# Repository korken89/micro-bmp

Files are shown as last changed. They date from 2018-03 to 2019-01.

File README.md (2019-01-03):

# Micro Black Magic Probe (µBMP)

A small [Black Magic Probe](https://github.com/blacksphere/blackmagic) based on the pinout of the STLink V2 support firmware. Connections has been added for the support of SWO, while the UART pinout is also available. Designed to stick directly into a USB port, without cable.

## Changes

### v1.4.1

* Reinforced the USB-C plug's mounting pads

### v1.4

* Changed to USB-C plug

### v1.3

* Added LED on the 5V line to see when the fuse is "blown"
* Removed panelized boards, to be updated later

### v1.2

* Removed component designators to clean up the PCB, the designators are available in the Gerbers
* Consolidated components, using resistor arrays and 8ch ESD/EMI filter
* Now have ESD/EMI protection on the outputs
* Added fuse of 5V line

### v1.0

* First release
* Tested and working

## Resources

### Schematics

A PDF print of the schematic are available in `ubmp_v1_3.pdf`.

### Programming instructions

Clone and build `stlink` unless you already have it:

```bash
cd ~/git
git clone --recursive https://github.com/texane/stlink
cd stlink
make -j4
```

Clone and build the firmware for `Black Magic Probe`, note to use `stlink` as `PROBE_HOST`:

```bash
cd ~/git
git clone --recursive https://github.com/blacksphere/blackmagic.git
cd blackmagic
cd libopencm3
make -j4 lib
cd ../src
make -j4 PROBE_HOST=stlink
```

Flash the `uBMP`:

```bash
cp ../../stlink/build/Release/st-flash .
./st-flash erase
./st-flash write blackmagic_dfu.bin 0x8000000
./st-flash --reset write blackmagic.bin 0x8002000
```

## Images

### USB-C version (v1.4)
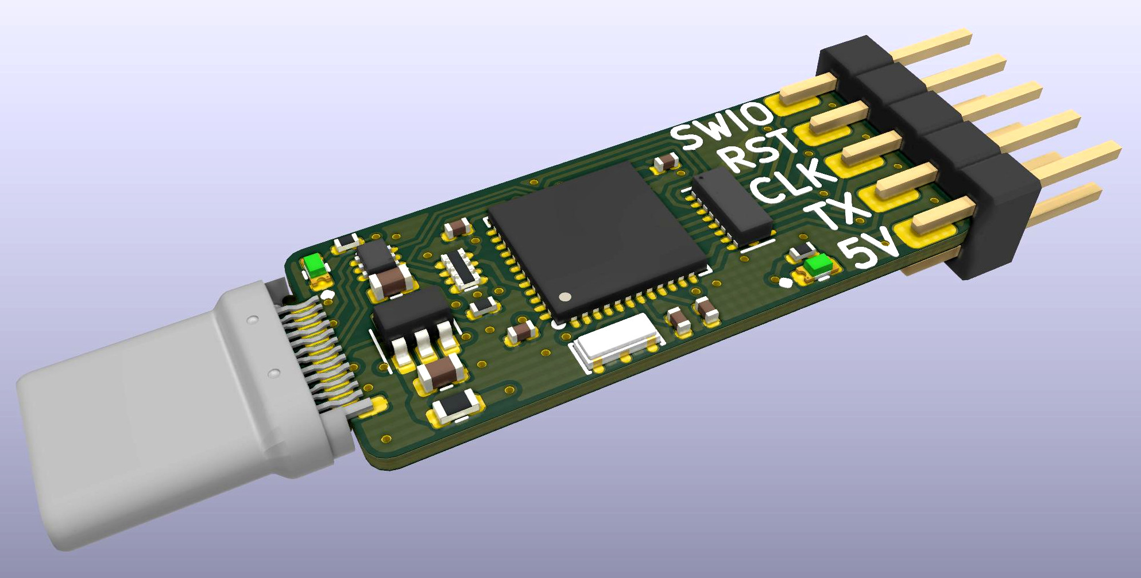
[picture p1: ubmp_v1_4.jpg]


### Second batch (v1.2)
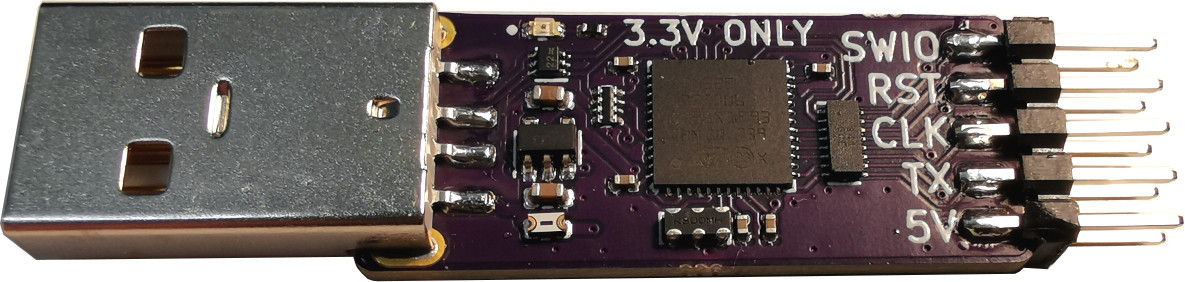
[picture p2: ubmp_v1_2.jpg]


### First batch (v1.0)

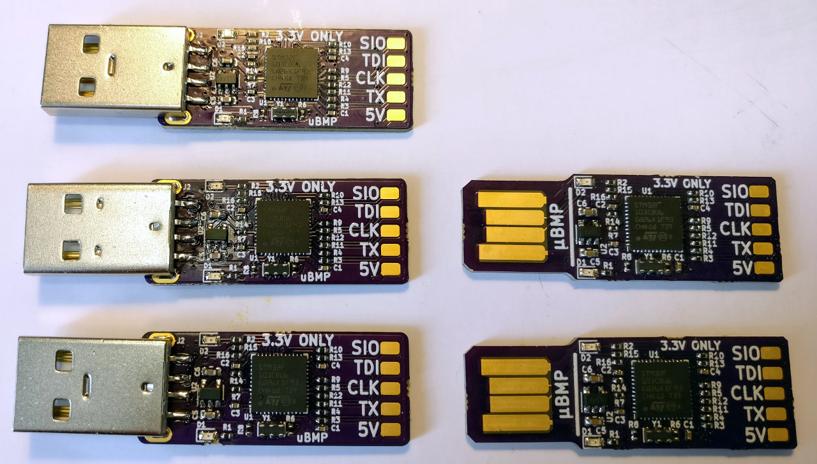
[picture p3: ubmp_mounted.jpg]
Mounted

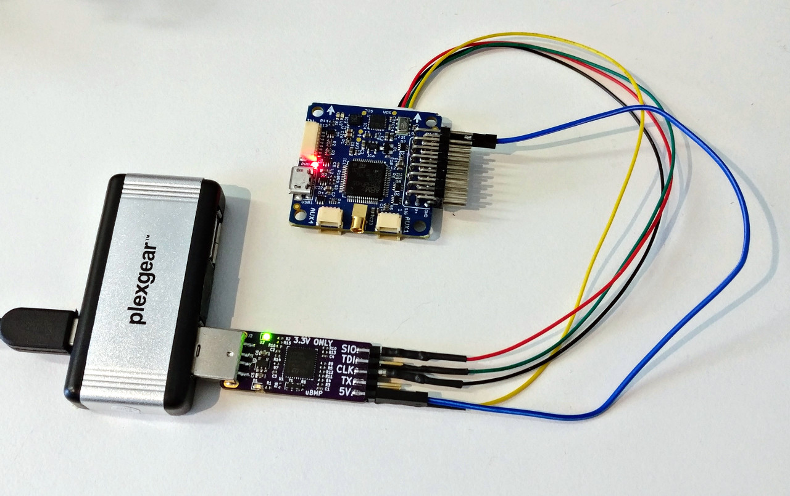
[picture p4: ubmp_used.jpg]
In use


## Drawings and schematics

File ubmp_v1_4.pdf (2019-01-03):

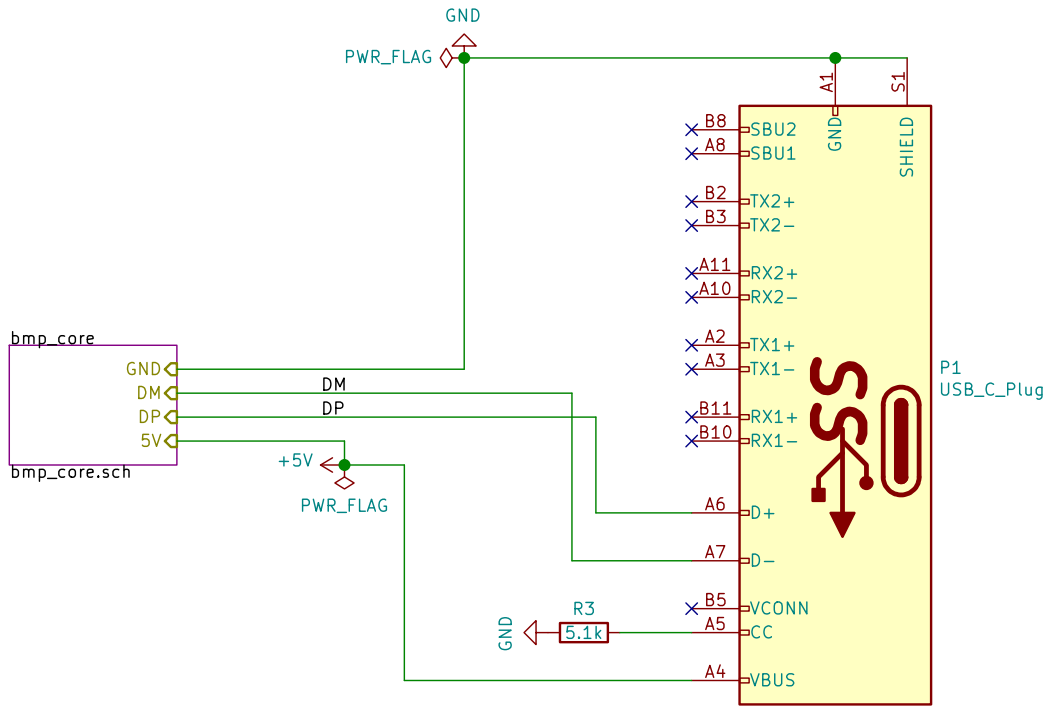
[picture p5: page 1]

Note that this board is designed to work with the
STLink V2 version of Black Magic Probe firmware.
Design available at: github.com/korken89/micro-bmp

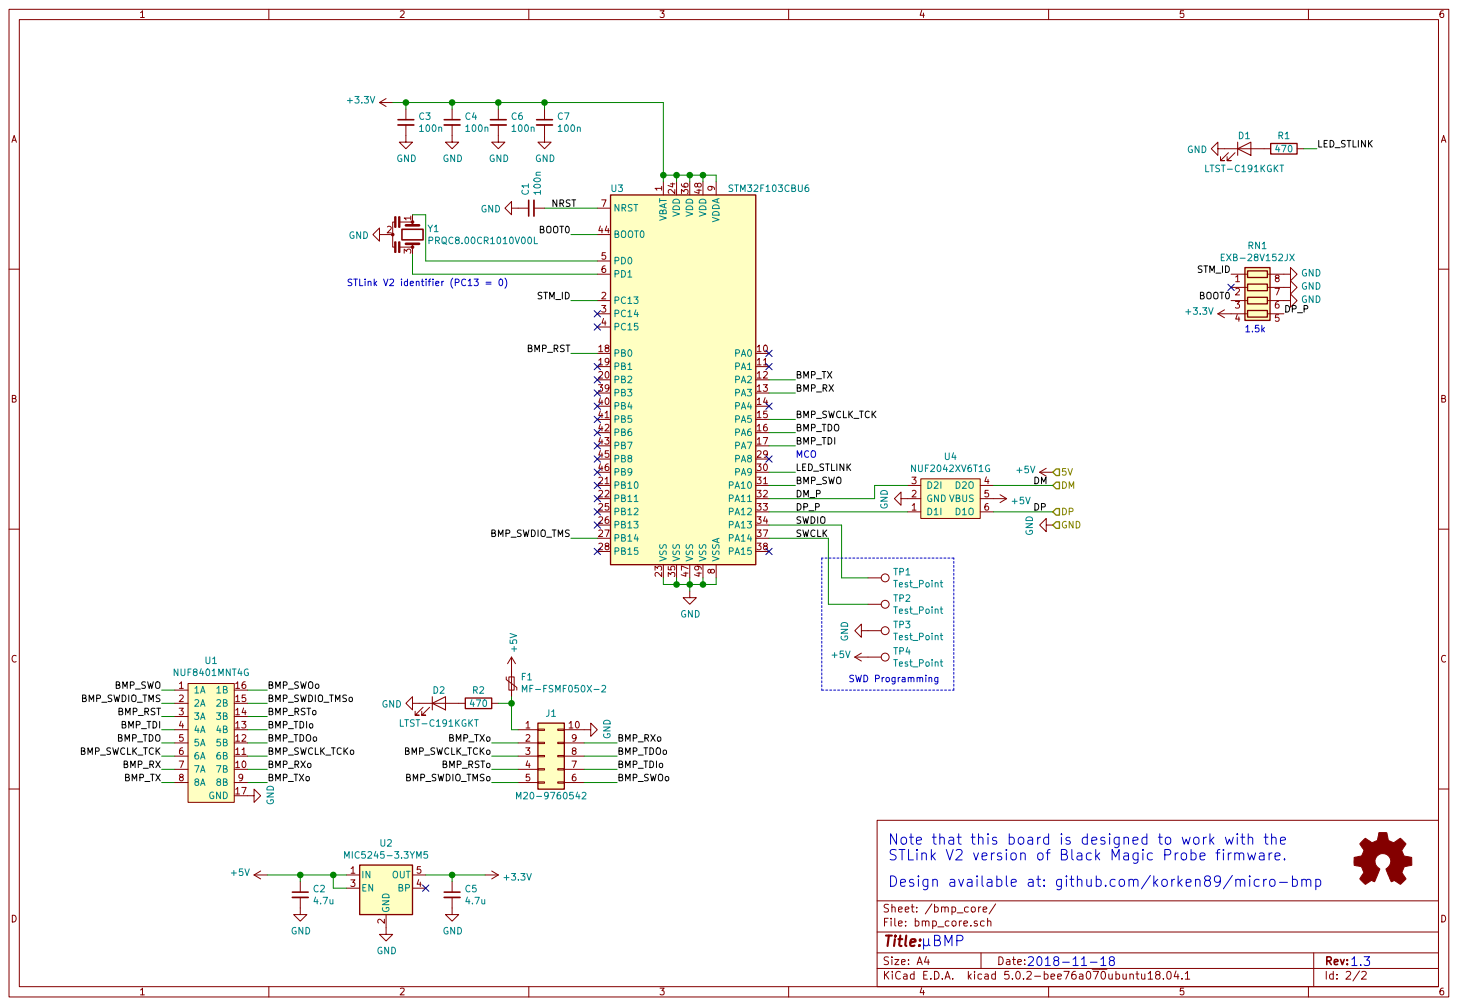
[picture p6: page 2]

9 VSS 23 VSS 35 VSS 47 VSS 49 VSSA

2 EN 3 BP 4 OUT 5 U2 MIC5245-3.3YM5 GND

STLink V2 version of Black Magic Probe firmware.
Design available at: github.com/korken89/micro-bmp

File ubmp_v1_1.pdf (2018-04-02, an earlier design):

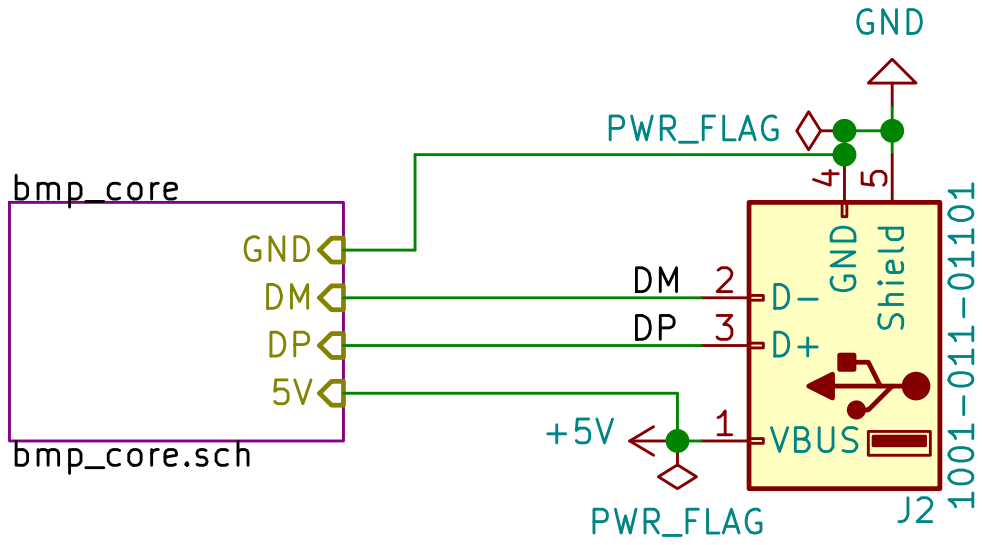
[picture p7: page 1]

Note that this board is designed to work with the
STLink V2 version of Black Magic Probe firmware.
Design available at: github.com/korken89/micro-bmp

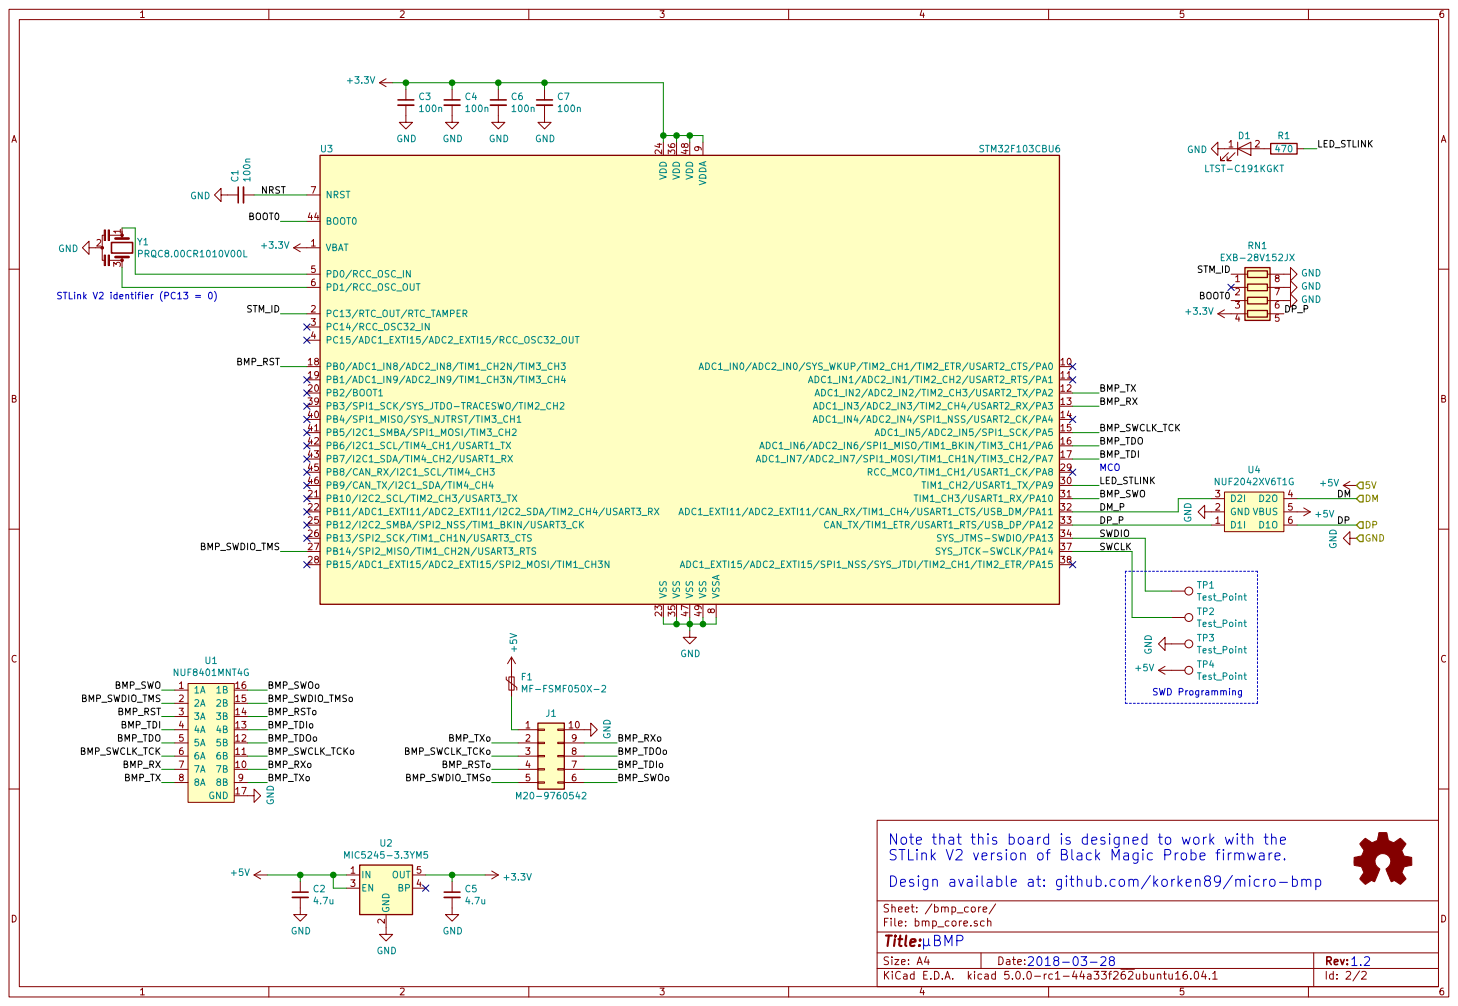
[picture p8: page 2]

9 VSS 23 VSS 35 VSS 47 VSS 49 VSSA

2 EN 3 BP 4 OUT 5 U2 MIC5245-3.3YM5 GND

STLink V2 version of Black Magic Probe firmware.
Design available at: github.com/korken89/micro-bmp

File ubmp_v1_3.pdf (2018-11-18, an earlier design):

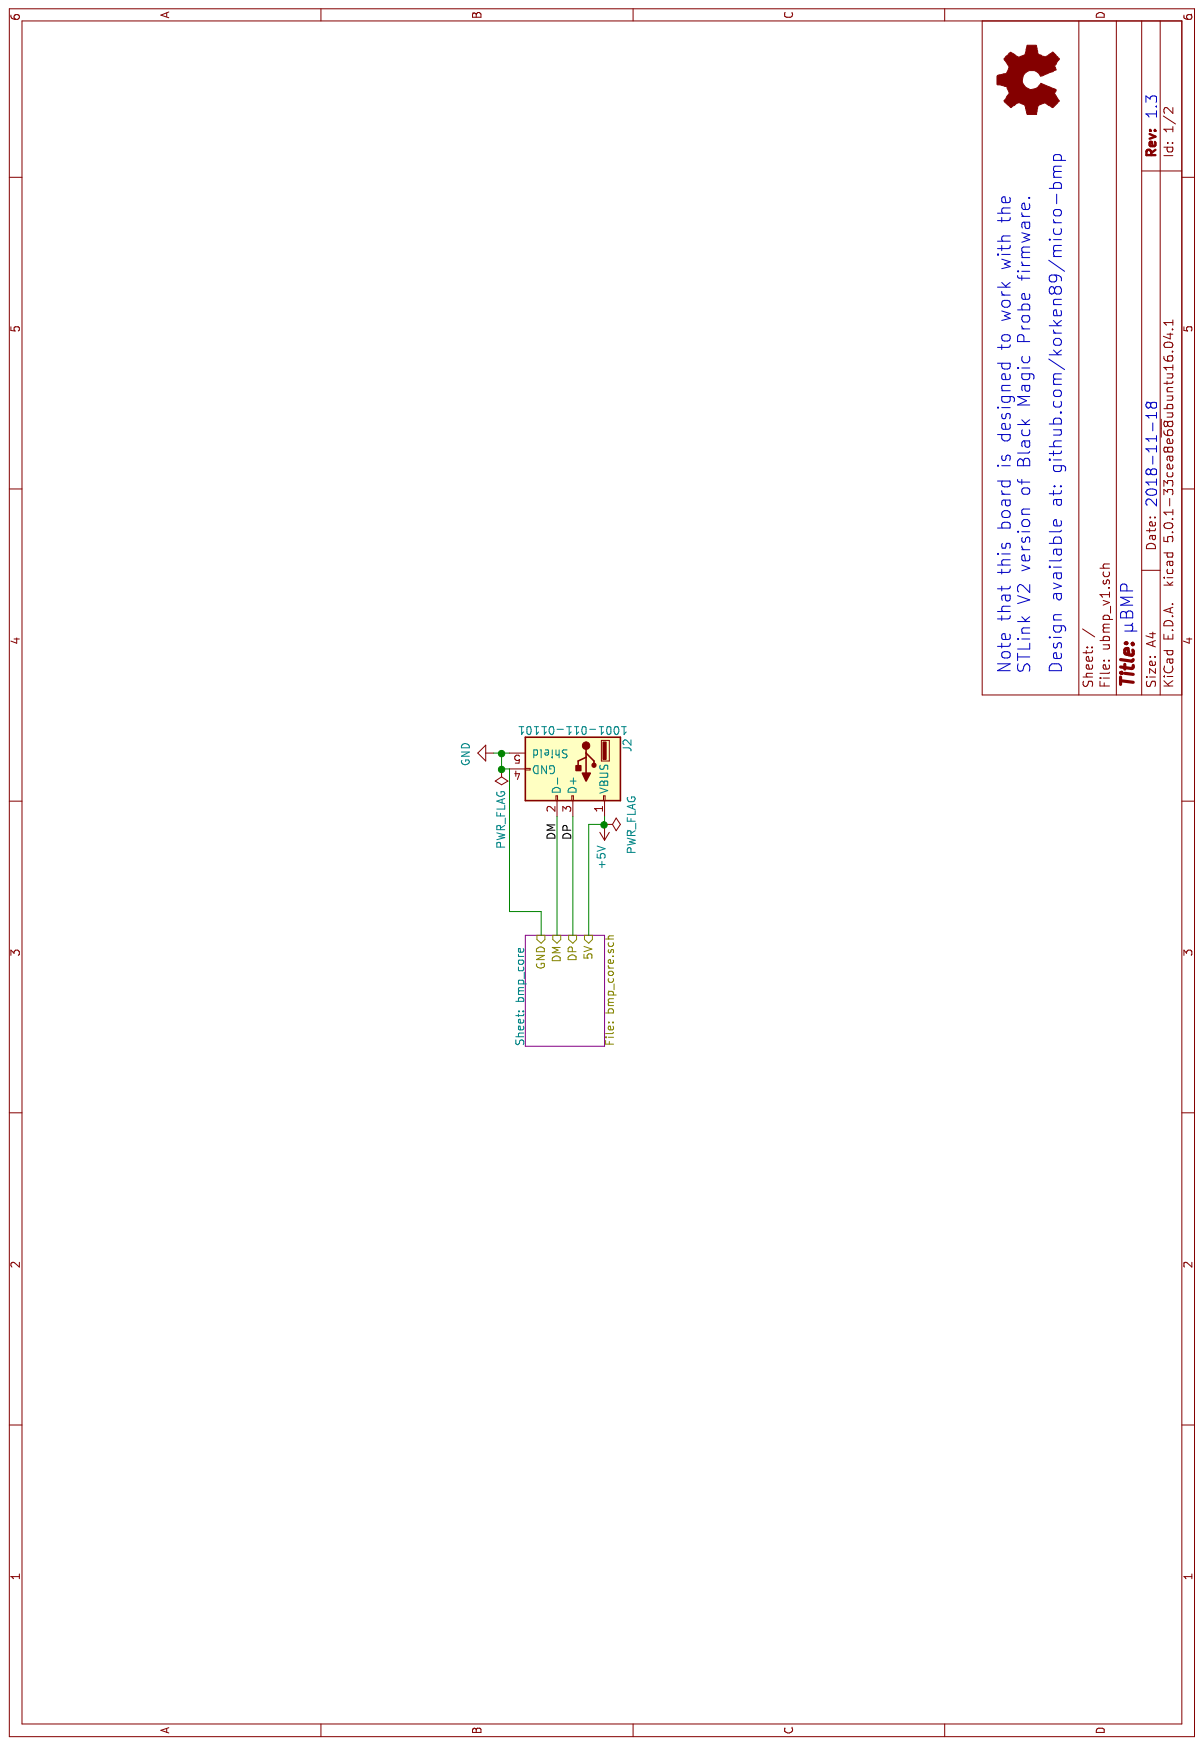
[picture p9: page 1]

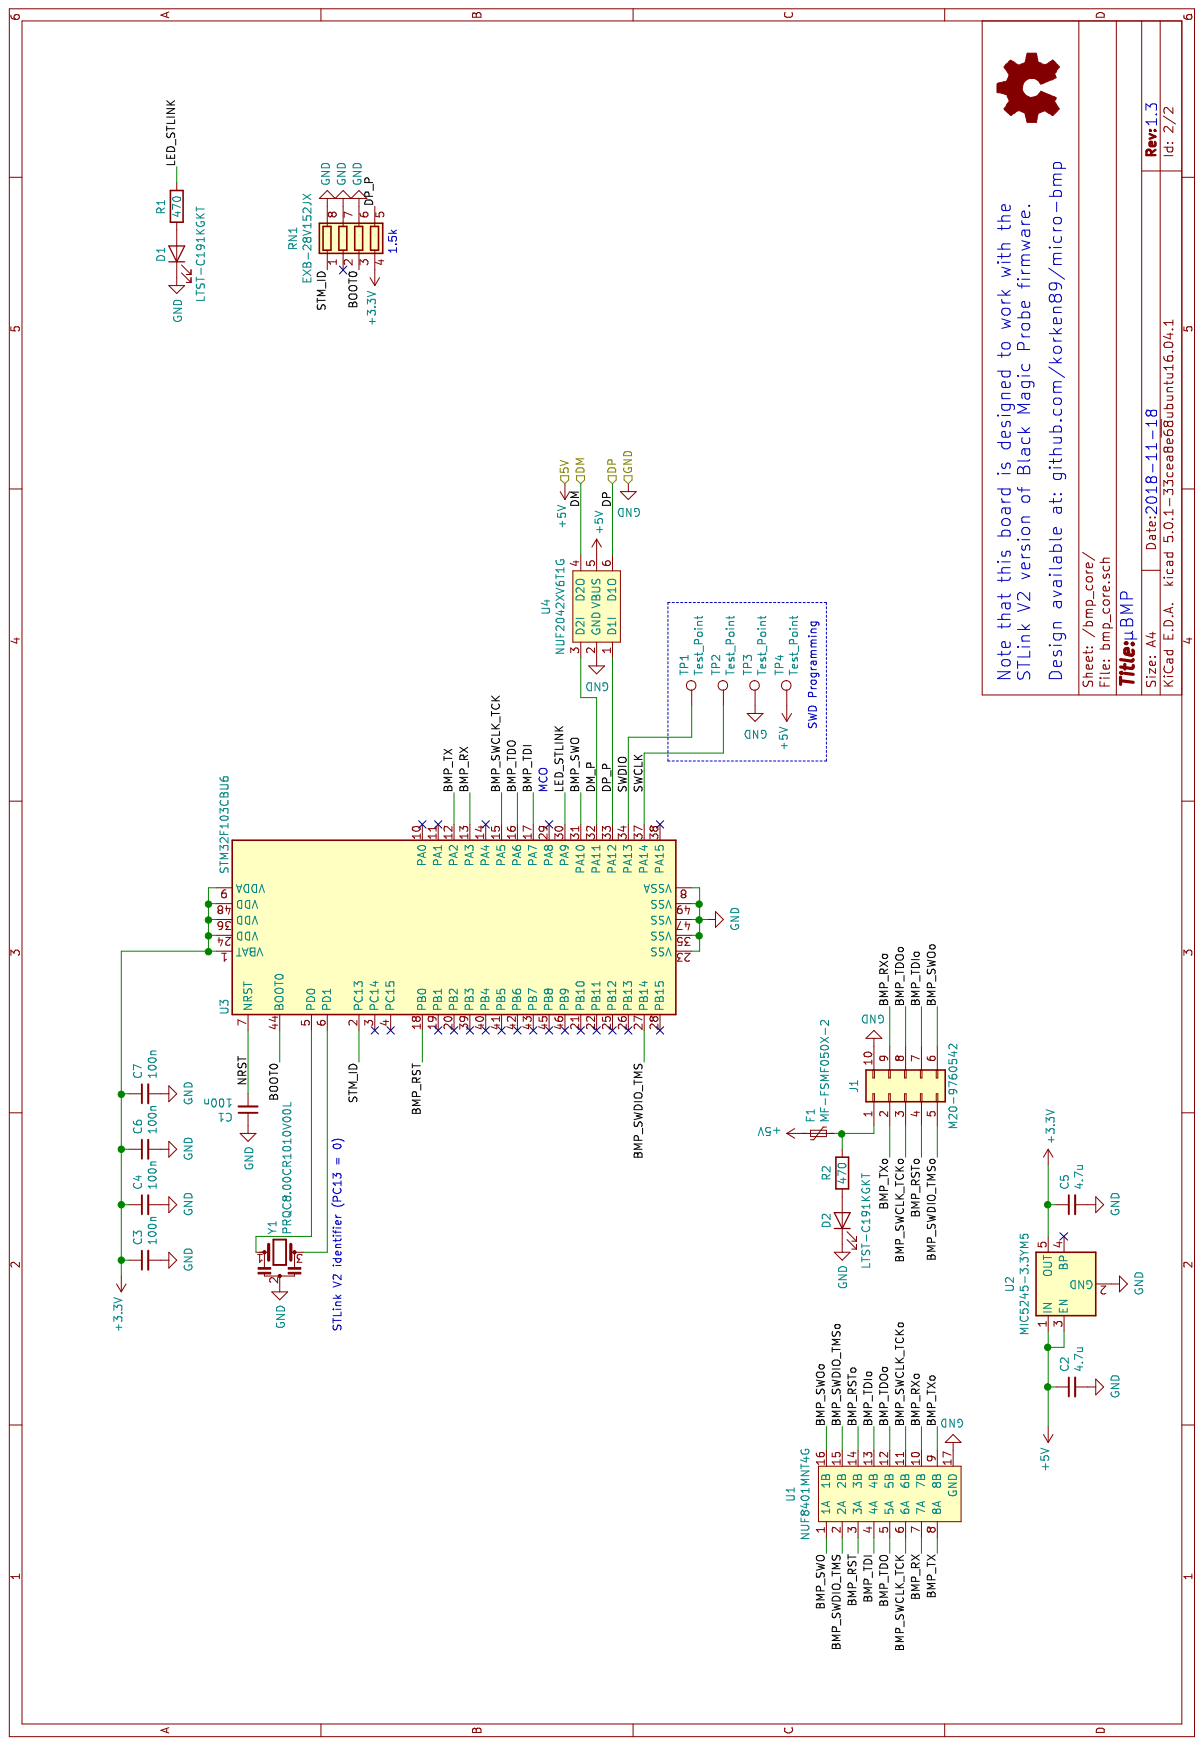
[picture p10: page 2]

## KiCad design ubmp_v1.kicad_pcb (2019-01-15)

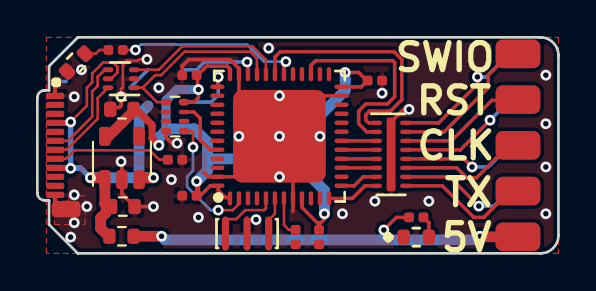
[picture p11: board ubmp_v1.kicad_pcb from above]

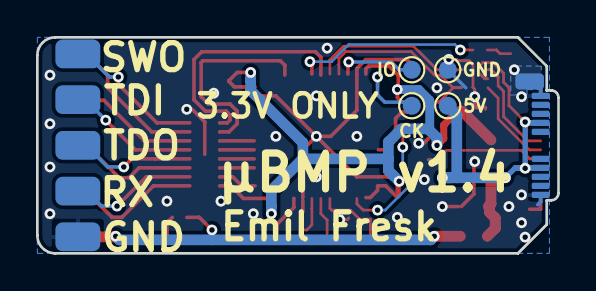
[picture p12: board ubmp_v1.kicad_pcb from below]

Board: 2 copper layers, 29.0 x 12.0 mm, 25 parts (4 on the bottom side), 35 nets.

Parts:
C1, C3, C4, C6, C7: 100n; C_0402_1005Metric_Rounded
C2, C5: 4.7u; C_0603_1608Metric_Rounded
D1, D2: LTST-C191KGKT; LEDC1608X60
F1: MF-FSMF050X-2; R_0603_1608Metric_Rounded
J1: M20-9760542; 2x5_2.54mm_side
P1: USB_C_Plug; USB_C_Plug_Molex_1054440001
R1, R2: 470; R_0402_1005Metric_Rounded
R3: 5.1k; R_0402_1005Metric_Rounded
RN1: EXB-28V152JX; R_Array_Convex_4x0402
TP1, TP2, TP3, TP4: Test_Point; TestPoint_Pad_D1.0mm
U1: NUF8401MNT4G; DFN-16-1EP_1.6x4mm_P0.5mm
U2: MIC5245-3.3YM5; SOT-23-5
U3: STM32F103CBU6; QFN-48-1EP_7x7mm_P0.5mm_EP5.15x5.15mm
U4: NUF2042XV6T1G; DFN-6-1EP_1.2x1.6mm_P0.5mm
Y1: PRQC8.00CR1010V00L; Resonator_3pin_3.2x1.3mm

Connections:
+3V3: C3.1, C4.1, C5.1, C6.1, C7.1, RN1.4, U2.5, U3.1, U3.9, U3.24, U3.36, U3.48
+5V: C2.1, F1.2, P1.A4, P1.A9, P1.B4, P1.B9, TP4.1, U2.1, U2.3, U4.5
/DM: P1.A7, U4.4
/DP: P1.A6, U4.6
/bmp_core/BMP_RST: U1.3, U3.18
/bmp_core/BMP_RSTo: J1.4, U1.14
/bmp_core/BMP_RX: U1.7, U3.13
/bmp_core/BMP_RXo: J1.9, U1.10
/bmp_core/BMP_SWCLK_TCK: U1.6, U3.15
/bmp_core/BMP_SWCLK_TCKo: J1.3, U1.11
/bmp_core/BMP_SWDIO_TMS: U1.2, U3.27
/bmp_core/BMP_SWDIO_TMSo: J1.5, U1.15
/bmp_core/BMP_SWO: U1.1, U3.31
/bmp_core/BMP_SWOo: J1.6, U1.16
/bmp_core/BMP_TDI: U1.4, U3.17
/bmp_core/BMP_TDIo: J1.7, U1.13
/bmp_core/BMP_TDO: U1.5, U3.16
/bmp_core/BMP_TDOo: J1.8, U1.12
/bmp_core/BMP_TX: U1.8, U3.12
/bmp_core/BMP_TXo: J1.2, U1.9
/bmp_core/BOOT0: RN1.3, U3.44
/bmp_core/DM_P: U3.32, U4.3
/bmp_core/DP_P: RN1.5, U3.33, U4.1
/bmp_core/LED_STLINK: R1.1, U3.30
/bmp_core/NRST: C1.2, U3.7
/bmp_core/STM_ID: RN1.1, U3.2
/bmp_core/SWCLK: TP2.1, U3.37
/bmp_core/SWDIO: TP1.1, U3.34
GND: C1.1, C2.2, C3.2, C4.2, C5.2, C6.2, C7.2, D1.1, D2.1, J1.10, P1.A1, P1.A12, P1.B1, P1.B12, P1.S1, R3.2, RN1.6, RN1.7, RN1.8, TP3.1, U1.17, U2.2, U3.8, U3.23, U3.35, U3.47, U3.49, U4.2, Y1.2
unnamed: D1.2, R1.2
unnamed: D2.2, R2.2
unnamed: F1.1, J1.1, R2.1
unnamed: P1.A5, R3.1
unnamed: U3.5, Y1.1
unnamed: U3.6, Y1.3

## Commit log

2018-02-05 PCB layout
    [ubmp_v1r1.kicad_pcb]
2018-02-05 PCB layout done
    [ubmp_v1r1.kicad_pcb, ubmp_v1r1.sch]
2018-02-05 Added text to PCB
    [ubmp_v1r1.kicad_pcb]
2018-02-05 Added OSHW + README
    [ubmp_v1r1.sch]
2018-02-05 More GND
    [ubmp_v1r1.kicad_pcb]
2018-02-05 Minor silk fix
    [ubmp_v1r1.kicad_pcb]
2018-02-06 Updated schematic for STLink V2 clone
    [ubmp_v1r1.kicad_pcb, ubmp_v1r1.sch]
2018-02-06 Updated board for STLink V2 clone, added schematic print, updated images, updated README
    [ubmp_v1r1.kicad_pcb, ubmp_v1r1.sch]
2018-02-06 Added SWD PROG text
    [ubmp_v1r1.kicad_pcb]
2018-02-06 Added gerbers
    [ubmp_v1r1-B.Cu.gbr, ubmp_v1r1-B.Mask.gbr, ubmp_v1r1-B.SilkS.gbr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]
2018-02-08 Minor improvements
    [ubmp_v1r1.kicad_pcb]
2018-02-09 Added size text and regenerated gerbers
    [ubmp_v1r1-B.Cu.gbr, ubmp_v1r1-B.Mask.gbr, ubmp_v1r1-B.SilkS.gbr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]
2018-02-09 Fixed corners and updated images
    [ubmp_v1r1-B.Cu.gbr, ubmp_v1r1-B.Mask.gbr, ubmp_v1r1-B.SilkS.gbr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]
2018-02-09 Changed placement of OSHW logo
    [ubmp_v1r1-B.Cu.gbr, ubmp_v1r1-B.Mask.gbr, ubmp_v1r1-B.SilkS.gbr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]
2018-02-09 Updated fab layer
    [ubmp_v1r1.kicad_pcb]
2018-02-11 Made pour outline follow board outline
    [ubmp_v1r1.kicad_pcb]
2018-02-11 Tested making a 4x3 panel
    [ubmp_v1r1_panel.kicad_pcb]
2018-02-11 Testing more with panel
    [ubmp_v1r1_panel.kicad_pcb]
2018-02-12 Added size to panel
    [ubmp_v1r1_panel.kicad_pcb]
2018-02-12 Fixed rounded pads and bad soldermask width on 0402
    [ubmp_v1r1-B.Cu.gbr, ubmp_v1r1-B.Mask.gbr, ubmp_v1r1-B.SilkS.gbr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]
2018-02-12 Silk fix
    [ubmp_v1r1-B.Cu.gbr, ubmp_v1r1-B.Mask.gbr, ubmp_v1r1-B.SilkS.gbr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]
2018-02-17 Updated USB footprint
    [ubmp_v1r1.kicad_pcb]
2018-02-17 Fixed footprint associations in sch
    [ubmp_v1r1.kicad_pcb, ubmp_v1r1.sch]
2018-02-17 Updated gerbers
    [ubmp_v1r1-B.Cu.gbr, ubmp_v1r1-B.Mask.gbr, ubmp_v1r1-B.SilkS.gbr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]
2018-02-17 Footprint fixes
    [ubmp_v1r1.sch]
2018-02-17 Added script to rename gerbers
    [ubmp_v1r1-Dwgs.User.gbr, ubmp_v1r1-F.Paste.gbr, ubmp_v1r1.GBL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]
2018-02-18 Changed to USB connector, 1.6mm PCB was too thin
    [ubmp_v1r1-Dwgs.User.gbr, ubmp_v1r1-F.Paste.gbr, ubmp_v1r1.GBL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]
2018-03-24 Added images for mounted uBMP + added flash instructions
2018-03-25 Now more compatible with STLink-v2
    Changes:
    * Fixed 0603 cap spacing
    * Added fuse to 5V line
    * Connected unused signals from STLink schematic
    * Connected BOOT1 to GND
    * Removed yellow LED
    * Updated width of USB connector pads for easier soldering
    [ubmp_v1r1-Dwgs.User.gbr, ubmp_v1r1-F.Paste.gbr, ubmp_v1r1.GBL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]
2018-03-25 Updated PCB version number, generated new schematic
    [ubmp_v1r1-Dwgs.User.gbr, ubmp_v1r1-F.Paste.gbr, ubmp_v1r1.GBL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]
2018-03-26 Updated reset circuit and updated silkscreen layout
    [ubmp_v1r1-Dwgs.User.gbr, ubmp_v1r1-F.Paste.gbr, ubmp_v1r1.GBL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]
2018-03-26 Updated schematic PDF and removed renders from README
2018-03-26 Regenerated gerbers to include slots in USB connector
    [ubmp_v1r1-Dwgs.User.gbr, ubmp_v1r1-F.Paste.gbr, ubmp_v1r1.GBL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]
2018-03-26 Bumped version number
    [ubmp_v1r1.sch]
2018-03-26 Reverted STlink compatibility changes and updated a lot of footprints
    [ubmp_v1r1-Dwgs.User.gbr, ubmp_v1r1-F.Paste.gbr, ubmp_v1r1.GBL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]
2018-03-26 Regernerated gerbers
    [ubmp_v1r1-Dwgs.User.gbr, ubmp_v1r1-F.Paste.gbr, ubmp_v1r1.GBL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]
2018-03-27 Renamed and added USBPCB version as seperate project
    [ubmp_v1.kicad_pcb, ubmp_v1.sch, ubmp_v1_pcbusb.kicad_pcb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]
2018-03-27 Regenerated gerbers
    [ubmp_v1-Dwgs.User.gbr, ubmp_v1-F.Paste.gbr, ubmp_v1.GBL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]
2018-03-27 Bumped schematic date
    [ubmp_v1.sch, ubmp_v1_pcbusb.sch]
2018-03-28 Changed all 100 and 22 ohm resistors to ESD chips with built in resistors
    [ubmp_v1_pcbusb.kicad_pcb, ubmp_v1_pcbusb.sch]
2018-03-29 Split into hierarchical sheep
    [bmp_core.sch, ubmp_v1.kicad_pcb, ubmp_v1.sch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]
2018-03-29 Updated pinput
    [bmp_core.sch, ubmp_v1.kicad_pcb, ubmp_v1.sch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]
2018-03-30 Moved libs to external repo
    [bmp_core.sch, ubmp_v1.kicad_pcb, ubmp_v1.sch]
2018-03-30 Updated PCB USB version
    [ubmp_v1-Dwgs.User.gbr, ubmp_v1-F.Paste.gbr, ubmp_v1.GBL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]
2018-03-30 Updated PCB locks and panel
    [ubmp_v1.kicad_pcb, ubmp_v1_panel.kicad_pcb, ubmp_v1_pcbusb.kicad_pcb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]
2018-03-30 Updated 3d kicad_libs
2018-03-31 Updated components + libs and changed to 1.5k resistor arrary
    [bmp_core.sch, ubmp_v1.kicad_pcb, ubmp_v1.sch]
2018-03-31 Minor PCB fixes, added OSHW logo
    [ubmp_v1.kicad_pcb]
2018-03-31 Updated USBPCB version and panel
    [bmp_core.sch, ubmp_v1.kicad_pcb, ubmp_v1_panel.kicad_pcb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]
2018-04-01 Improved ground layout
    [ubmp_v1.kicad_pcb]
2018-04-01 Fixed through holes on USB connector to be NPTH
    [ubmp_v1.kicad_pcb, ubmp_v1.sch]
2018-04-02 Updated part numbers
    [bmp_core.sch, ubmp_v1.kicad_pcb, ubmp_v1.sch]
2018-04-02 Regenerated PDF schematic
2018-04-02 Improved resistor array pad sizes
    [ubmp_v1.kicad_pcb]
2018-04-03 Bumped schematic date and added value to resistor array
    [bmp_core.sch, ubmp_v1.sch]
2018-04-04 Updated kicad_libs
2018-04-14 Update 0402 and 0603 to IPC least
    [ubmp_v1.kicad_pcb]
2018-04-15 Added OSHW logo
    [ubmp_v1.kicad_pcb]
2018-04-15 Updated panel for hand assembly
    [ubmp_v1_panel.kicad_pcb]
2018-11-18 v1.3 release
    [bmp_core.sch, ubmp_v1.kicad_pcb, ubmp_v1.sch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]
2019-01-03 Moved to USB-C plug
    [ubmp_v1.kicad_pcb, ubmp_v1.sch]
2019-01-03 Updated gitignore to not add gerbers folder
2019-01-03 Reinforced the USB-C anchor pads
    [ubmp_v1.kicad_pcb]
2019-01-15 Improved USB-C mounting even more
    [ubmp_v1.kicad_pcb]
2019-01-15 Fixed corners to better fit the USB-C connector
    [ubmp_v1.kicad_pcb]
